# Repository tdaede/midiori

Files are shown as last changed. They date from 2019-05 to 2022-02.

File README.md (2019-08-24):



# Installation

1. Remove a cover plate from a free x68000 expansion slot.
2. Slide card into expansion plate until it seats. It will take some force.
3. Install 3d printed cover plate.
4. Attach OUT connector to MIDI in of your synthesizer.
5. (optional) Run LINE OUT from the x68000 to the LINE IN of your synthesizer's internal mixer.

# Compatibility

A list of tested games is available [here](docs/GAMES.md).

# Changelog

See [here](docs/CHANGELOG.md).

# Differences from midiori v1

- MIDI IN and THRU ports are not implemented.
- FIFO-Rx and FIFO-IRx are not implemented.
- FIFO-ITx start/stop/clock messages are not implemented.
- SYNC and CLICK are not implemented.
- Sequencer is not implemented.
- GPIO is not implemented.
- Address is locked to 0xeafa00.
- IRQ is locked to slot+2.
- Baud rate is locked to 31250 bps, 8n1.
- 32-byte, null terminated version string, readable by writing
  the index (0-31) to 0xF4 and reading the current byte from 0xF5.
- 68k bus is implemented natively and timings are generally faster.

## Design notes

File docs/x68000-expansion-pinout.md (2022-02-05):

# X68000 Expansion Pinout
As described by [_Outside X68000_](https://archive.org/stream/OutsideX680001993/Outside_X68000_1993#page/n51/mode/2up). Translated by Google.

| Pin # | Description | I/O | Comment |
|---|---|-----|---|
|A1 | GND | ... | Ground  |
|A2 | 20MHz | O | 20MHz clock |
|A3 | GND | ... | Ground  |
|A4 | DB0 | I/O | Data bus |
|A5 | DB1 | I/O | Data bus |
|A6 | DB2 | I/O | Data bus |
|A7 | DB3 | I/O | Data bus |
|A8 | DB4 | I/O | Data bus |
|A9 | DB5 | I/O | Data bus |
|A10 | DB6 | I/O | Data bus |
|A11 | GND | ... | Ground  |
|A12 | DB7 | I/O | Data bus |
|A13 | DB8 | I/O | Data bus |
|A14 | DB9 | I/O | Data bus |
|A15 | DB10 | I/O | Data bus |
|A16 | DB11 | I/O | Data bus |
|A17 | DB12 | I/O | Data bus |
|A18 | DB13 | I/O | Data bus |
|A19 | DB14 | I/O | Data bus |
|A20 | DB15 | I/O | Data bus |
|A21 | GND | ... | Ground |
|A22 | +12V | O | +12V DC power supply |
|A23 | +12V | O | +12V DC power supply |
|A24 | FC0 | I/O | Function code |
|A25 | FC1 | I/O | Function code |
|A26 | FC2 | I/O | Function code |
|A27 | ~AS | I/O | Address strobe |
|A28 | ~LDS | I/O | Lower data strobe |
|A29 | ~UDS | I/O | Upper data strobe |
|A30 | R/~W | I/O | Read/write ("L" = Write) |
|A31 | --- | ... | Unused (key?) |
|A32 | -12V | O | -12V DC power supply |
|A33 | -12V | O | -12V DC power supply |
|A34 | ~VMA | O | Address bus enabled |
|A35 | -EXVPA | I | 6800-series peripheral device access signal |
|A36 | ~DTACK | I/O | Data transfer completed |
|A37 | ~EXRESET | O | External reset |
|A38 | ~HALT | I/O | CPU halt request |
|A39 | ~EXBERR | I/O | Bus error |
|A40 | ~EXPWON | I | Soft-power ON request |
|A41 | GND | ... | Ground |
|A42 | Vcc2 | O | +5V standby power (always on) |
|A43 | Vcc2 | O | +5V standby power (always on) |
|A44 | SELEN | O | Row/column address switching |
|A45 | CASRDEN | O | Main memory CAS signal (when reading) |
|A46 | CASWRL | O | CAS signal for writing lower data |
|A47 | CASWRU | O | CAS signal for writing upper data |
|A48 | INH2 | O | Refresh cycle display signal |
|A49 | Vcc1 | O | +5V DC power supply |
|A50 | Vcc1 | O | +5V DC power supply |
|B1 | GND | ... | Ground |
|B2 | 10MHz | O | 10MHz clock signal |
|B3 | ~10MHz | O | 10MHz clock signal (inverted) |
|B4 | E | O | 6800-series peripheral device clock |
|B5 | AB1 | I/O | Address bus |
|B6 | AB2 | I/O | Address bus |
|B7 | AB3 | I/O | Address bus |
|B8 | AB4 | I/O | Address bus |
|B9 | AB5 | I/O | Address bus |
|B10 | AB6 | I/O | Address bus |
|B11 | GND | ... | Ground |
|B12 | AB7 | I/O | Address bus |
|B13 | AB8 | I/O | Address bus |
|B14 | AB9 | I/O | Address bus |
|B15 | AB10 | I/O | Address bus |
|B16 | AB11 | I/O | Address bus |
|B17 | AB12 | I/O | Address bus |
|B18 | AB13 | I/O | Address bus |
|B19 | AB14 | I/O | Address bus |
|B20 | AB15 | I/O | Address bus |
|B21 | GND | ... | Ground |
|B22 | AB16 | I/O | Address bus |
|B23 | AB17 | I/O | Address bus |
|B24 | AB18 | I/O | Address bus |
|B25 | AB19 | I/O | Address bus |
|B26 | AB20 | I/O | Address bus |
|B27 | AB21 | I/O | Address bus |
|B28 | AB22 | I/O | Address bus |
|B29 | AB23 | I/O | Address bus |
|B30 | IDDIR | O | Data bus buffer direction control |
|B31 | --- | ... | Unused (key?) |
|B32 | HSYNC | O | Horizontal sync signal |
|B33 | VSYNC | O | Vertical sync signal |
|B34 | ~DONE | O | DMA block transfer complete |
|B35 | ~DTC | I | DMA data transfer completed |
|B36 | ~EXREQ | I/O | DMA data transfer request |
|B37 | ~EXACK | O | DMA data transfer permission |
|B38 | ~EXPCL | I/O | DMA general purpose I/O signal |
|B39 | ~EXOWN | I/O | Bus release operation signal |
|B40 | ~EXNMI | I | NMI request signal |
|B41 | GND | ... | Ground |
|B42 | ~IRQ2-n | O | Level 2 interrupt request |
|B43 | ~IRQ4-n | O | Level 4 interrupt request |
|B44 | ~IACK2-n | O | Level 2 interrupt acknowledge |
|B45 | ~IACK4-n | O | Level 4 interrupt acknowledge |
|B46 | ~BR-n | O | Bus request |
|B47 | ~BG-n | O | Bus ground |
|B48 | ~BGACK | O | Bus ground acknowledge |
|B49 | Vcc1 | O | +5V DC power supply |
|B50 | Vcc1 | O | +5V DC power supply |

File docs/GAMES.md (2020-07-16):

Known working
---------------
* Akumajou Dracula
* Angel Dive
* Arcus Odyssey (登録)
* Atomic Robo-Kid (F1)
* Bleed Out
* Carat
* Cynthia (V2 only)
* Daimakaimura
* Detana!! TwinBee
* Die Bahnwelt
* Deadly Edge
* Etoile Princesse
* Final Fight
* Garou Densetsu
* Garou Densetsu 2
* Garou Densetsu Special
* Gemini Wing (F1)
* Genocide 2
* Geograph Seal
* Granada (10MHz)
* KU2
* Mahou Daisakusen
* Metal Orange EX
* Nemesis '90 Kai
* Parodius Da! (F3)
* Phalanx
* Sol-Feace (登録)
* Star Luster
* Street Fighter II
* Super Hang-On
* Super Street Fighter II
* Thunder Blade (F5)
* Xenon 2 (登録)

Broken
-------

Unknown
--------
* Gradius II - unknown how to configure
* Duel Fighter 2 - unknown how to configure
* Overtake - crashes on music playback start with both 1.1 and 2.1
* Square Resort - unknown how to configure

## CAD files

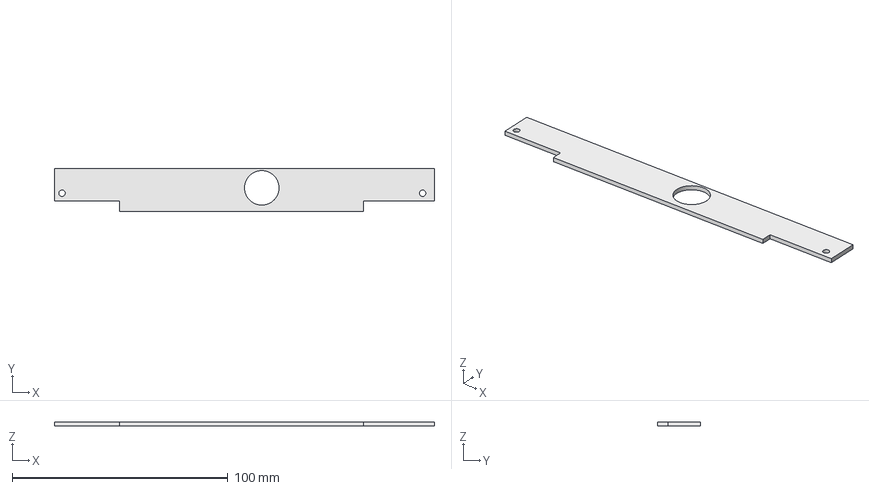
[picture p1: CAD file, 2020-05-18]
mech/midiori_2_plate_minidin_laser.FCStd
176.0 x 20.0 x 2.00 mm

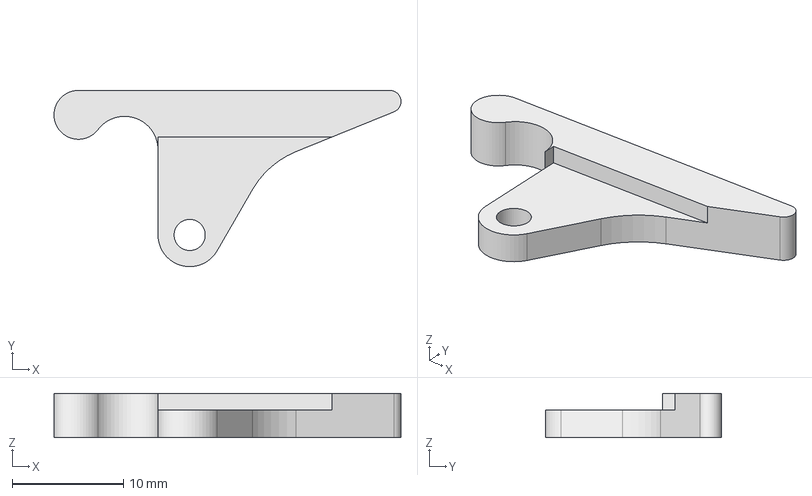
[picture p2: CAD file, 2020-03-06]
mech/x68k_pull.fcstd
31.2 x 15.8 x 4.00 mm

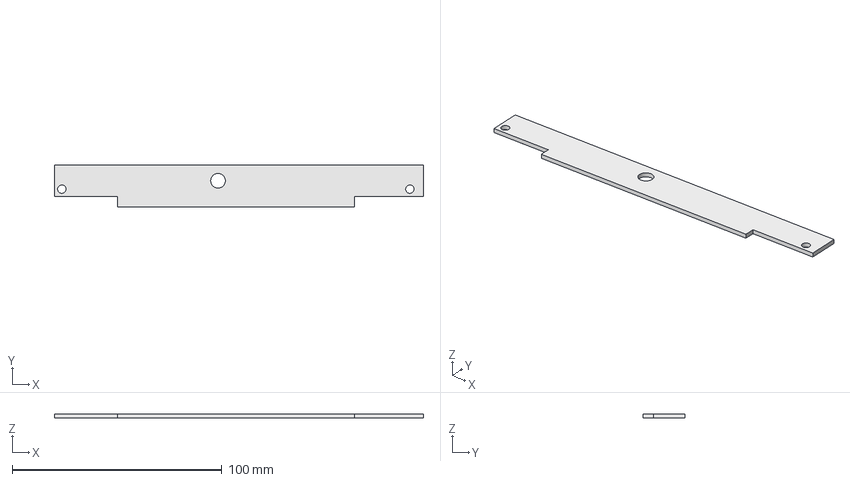
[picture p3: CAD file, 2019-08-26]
mech/midiori_2_plate_trs.FCStd
176.0 x 20.0 x 2.00 mm

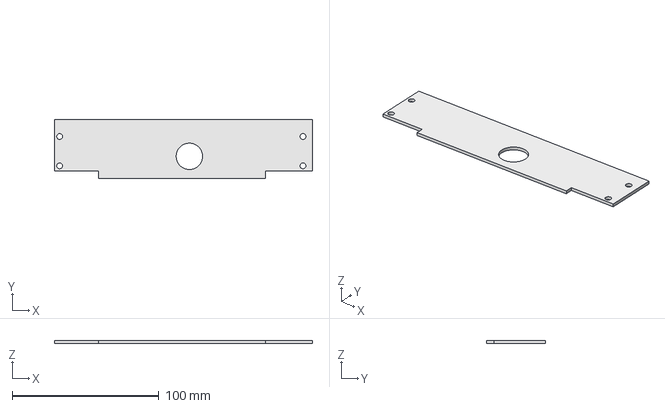
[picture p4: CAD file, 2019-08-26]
mech/midiori_2_plate_din.FCStd
176.0 x 40.0 x 2.00 mm

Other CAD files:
mech/midiori_2_plate_din.stl
mech/midiori_2_plate_trs.stl
mech/x68k_pull.stl

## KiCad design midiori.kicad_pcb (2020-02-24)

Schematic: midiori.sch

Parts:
C1, C2: 4.7uF; C_0805_2012Metric
C3, C4, C5, C6, C7, C9, C10, C11, C12, C13, C14, C15, C16, C17, C18, C19, C20, C21, C22, C23: 0.1uF; C_0805_2012Metric
C8: 0.1uF; C_0805_2012Metric_Pad1.15x1.40mm_HandSolder
H1, H2: MountingHole; MountingHole_3.2mm_M3_Pad
J1: x68000_expansion
J2: Conn_ARM_JTAG_SWD_10; PinHeader_2x05_P1.27mm_Vertical_SMD
J4: Mini-DIN-5; MD-50SM
R3: 10K; R_0805_2012Metric
R6, R9: 220; R_0805_2012Metric_Pad1.15x1.40mm_HandSolder
U1: 74LCX07; SOIC-14_3.9x8.7mm_P1.27mm
U2: AT25SF081-SSHD-X; SOIC-8_3.9x4.9mm_P1.27mm
U3: TLV73312PDBV; SOT-23-5
U4, U5, U6, U7, U8, U9: SN74LVC8T245DWR; SOIC-24W_7.5x15.4mm_P1.27mm
U10: ICE40HX1K-VQ100; QFP50P1600X1600X120-100N
U11: TLV73333PDBV; SOT-23-5
X1: 16MHz; Oscillator_SMD_SeikoEpson_SG8002CA-4Pin_7.0x5.0mm

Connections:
+1V2: C2.1, C16.1, C18.1, C20.1, C22.1, U3.5, U10.11 (VCC), U10.35 (VCC), U10.61 (VCC), U10.77 (VCC)
+3V3: C1.1, C3.1, C5.1, C7.1, C8.1, C10.1, C12.1, C14.1, C17.1, C19.1, C21.1, C23.1, J2.1 (VCC), R3.2, U1.14 (VCC), U2.3 (~WP~/IO2), U2.7 (~HOLD~/IO3), U2.8 (VCC), U3.1, U3.3, U4.23 (VCCB), U4.24 (VCCB), U5.23 (VCCB), U5.24 (VCCB), U6.23 (VCCB), U6.24 (VCCB), U7.23 (VCCB), U7.24 (VCCB), U8.23 (VCCB), U8.24 (VCCB), U9.23 (VCCB), U9.24 (VCCB), U10.6 (VCCIO_3), U10.14 (VCCIO_3), U10.22 (VCCIO_3), U10.31 (VCCIO_2), U10.38 (VCCIO_2), U10.50 (VCC_SPI), U10.58 (VCCIO_1), U10.67 (VCCIO_1), U10.75 (VPP_2V5), U10.88 (VCCIO_0), U10.92 (VCCIO_0), U11.5, X1.1 (OE), X1.4 (V+)
+5V: C4.1, C6.1, C9.1, C11.1, C13.1, C15.1, J1.A49 (+5V), J1.A50 (+5V), J1.B49 (+5V), J1.B50 (+5V), R6.1, U4.1 (VCCA), U4.2 (DIR), U5.1 (VCCA), U5.2 (DIR), U6.1 (VCCA), U6.2 (DIR), U7.1 (VCCA), U8.1 (VCCA), U8.2 (DIR), U9.1 (VCCA), U9.2 (DIR), U11.1, U11.3
/10MHz: J1.B3 (10MHz), U8.3 (A1)
/10m: U8.21 (B1), U10.97 (IOT_91)
/A: J1.A26 (FC2), U8.8 (A6)
/AB1: J1.B5 (AB1), U4.10 (A8)
/AB2: J1.B6 (AB2), U4.9 (A7)
/AB3: J1.B7 (AB3), U4.8 (A6)
/AB4: J1.B8 (AB4), U4.7 (A5)
/AB5: J1.B9 (AB5), U4.6 (A4)
/AB6: J1.B10 (AB6), U4.5 (A3)
/AB7: J1.B12 (AB7), U4.4 (A2)
/AB8: J1.B13 (AB8), U5.10 (A8)
/AB9: J1.B14 (AB9), U5.9 (A7)
/AB10: J1.B15 (AB10), U5.8 (A6)
/AB11: J1.B16 (AB11), U5.7 (A5)
/AB12: J1.B17 (AB12), U5.6 (A4)
/AB13: J1.B18 (AB13), U5.5 (A3)
/AB14: J1.B19 (AB14), U5.4 (A2)
/AB15: J1.B20 (AB15), U5.3 (A1)
/AB16: J1.B22 (AB16), U6.10 (A8)
/AB17: J1.B23 (AB17), U6.9 (A7)
/AB18: J1.B24 (AB18), U6.8 (A6)
/AB19: J1.B25 (AB19), U6.7 (A5)
/AB20: J1.B26 (AB20), U6.6 (A4)
/AB21: J1.B27 (AB21), U6.5 (A3)
/AB22: J1.B28 (AB22), U6.4 (A2)
/AB23: J1.B29 (AB23), U6.3 (A1)
/AS: J1.A27 (/AS), U8.7 (A5)
/B: J1.A25 (FC1), U8.9 (A7)
/C: J1.A24 (FC0), U8.10 (A8)
/DB0: J1.A4 (DB0), U7.10 (A8)
/DB1: J1.A5 (DB1), U7.9 (A7)
/DB2: J1.A6 (DB2), U7.8 (A6)
/DB3: J1.A7 (DB3), U7.7 (A5)
/DB4: J1.A8 (DB4), U7.6 (A4)
/DB5: J1.A9 (DB5), U7.5 (A3)
/DB6: J1.A10 (DB6), U7.4 (A2)
/DB7: J1.A12 (DB7), U7.3 (A1)
/DTACK: J1.A36 (/DTACK), U1.6
/EXRESET: J1.A37 (EXRESET), U8.4 (A2)
/IACK2: J1.B44 (/IACK2), U9.3 (A1)
/IACK4: J1.B45 (/IACK4), U9.4 (A2)
/IDDIR: J1.B30 (IDDIR), U7.2 (DIR), U9.5 (A3)
/IRQ2: J1.B42 (/IRQ2), U1.2
/IRQ4: J1.B43 (/IRQ4), U1.4
/LDS: J1.A28 (/LDS), U8.6 (A4)
/RW: J1.A30 (R/W), U8.5 (A3)
/a: U8.16 (B6), U10.3 (IOL_2A)
/a1: U4.14 (B8), U10.40 (IOB_41)
/a2: U4.15 (B7), U10.37 (IOB_37)
/a3: U4.16 (B6), U10.36 (IOB_34)
/a4: U4.17 (B5), U10.34 (IOB_36_GBIN4)
/a5: U4.18 (B4), U10.33 (IOB_35_GBIN5)
/a6: U4.19 (B3), U10.30 (IOB_30)
/a7: U4.20 (B2), U10.29 (IOB_29)
/a16: U6.14 (B8), U10.81 (IOT_77)
/a17: U6.15 (B7), U10.80 (IOT_75)
/a18: U6.16 (B6), U10.79 (IOT_74)
/a19: U6.17 (B5), U10.78 (IOT_73)
/a20: U6.18 (B4), U10.74 (IOR_72)
/a21: U6.19 (B3), U10.73 (IOR_71)
/a22: U6.20 (B2), U10.72 (IOR_70)
/a23: U6.21 (B1), U10.71 (IOR_69)
/ab8: U5.14 (B8), U10.18 (IOL_8A)
/ab9: U5.15 (B7), U10.16 (IOL_7B)
/ab10: U5.16 (B6), U10.15 (IOL_7A_GBIN6)
/ab11: U5.17 (B5), U10.13 (IOL_6B_GBIN7)
/ab12: U5.18 (B4), U10.12 (IOL_6A)
/ab13: U5.19 (B3), U10.10 (IOL_5B)
/ab14: U5.20 (B2), U10.9 (IOL_5A)
/ab15: U5.21 (B1), U10.8 (IOL_3B)
/as: U8.17 (B5), U10.2 (IOL_1B)
/b: U8.15 (B7), U10.4 (IOL_2B)
/c: U8.14 (B8), U10.7 (IOL_3A)
/d0: U7.14 (B8), U10.28 (IOB_28)
/d1: U7.15 (B7), U10.27 (IOB_27)
/d2: U7.16 (B6), U10.26 (IOB_26)
/d3: U7.17 (B5), U10.25 (IOL_12B)
/d4: U7.18 (B4), U10.24 (IOL_12A)
/d5: U7.19 (B3), U10.21 (IOL_10B)
/d6: U7.20 (B2), U10.20 (IOL_10A)
/d7: U7.21 (B1), U10.19 (IOL_8B)
/dtack: U1.5, U10.93 (IOT_87)
/exreset: U8.20 (B2), U10.99 (IOT_93)
/iack2: U9.21 (B1), U10.94 (IOT_88)
/iack4: U9.20 (B2), U10.95 (IOT_89)
/iddir: U9.19 (B3), U10.96 (IOT_90)
/irq2: U1.1, U10.90 (IOT_85_GBIN0)
/irq4: U1.3, U10.91 (IOT_86)
/lds: U8.18 (B4), U10.1 (IOL_1A)
/reset: J2.8 (NC/TDI), R3.1, U10.44 (CRESET_B)
/rw: U8.19 (B3), U10.100 (IOT_95)
/sck: J2.4 (SWDCLK/TCK), U2.6 (SCK), U10.48 (IOB_46_SCK)
/si: J2.2 (SWDIO/TMS), U2.5 (SI/IO0), U10.45 (IOB_44_SDO)
/so: J2.10 (~RESET~), U2.2 (SO/IO1), U10.46 (IOB_45_SDI)
/ss: J2.6 (SWO/TDO), U2.1 (~CS), U10.49 (IOB_47_SS)
/xltr_oe: U7.22 (OE), U10.51 (IOR_52)
GND: C1.2, C2.2, C3.2, C4.2, C5.2, C6.2, C7.2, C8.2, C9.2, C10.2, C11.2, C12.2, C13.2, C14.2, C15.2, C16.2, C17.2, C18.2, C19.2, C20.2, C21.2, C22.2, C23.2, J1.A1 (GND), J1.A3 (GND), J1.A11 (GND), J1.A21 (GND), J1.A41 (GND), J1.B1 (GND), J1.B11 (GND), J1.B21 (GND), J1.B41 (GND), J2.3 (GND), J2.5 (GND), J2.9 (GNDDetect), J4.2, U1.7 (GND), U1.11, U1.13, U2.4 (GND), U3.2, U4.3 (A1), U4.11 (GND), U4.12 (GND), U4.13 (GND), U4.21 (B1), U4.22 (OE), U5.11 (GND), U5.12 (GND), U5.13 (GND), U5.22 (OE), U6.11 (GND), U6.12 (GND), U6.13 (GND), U6.22 (OE), U7.11 (GND), U7.12 (GND), U7.13 (GND), U8.11 (GND), U8.12 (GND), U8.13 (GND), U8.22 (OE), U9.6 (A4), U9.7 (A5), U9.8 (A6), U9.9 (A7), U9.10 (A8), U9.11 (GND), U9.12 (GND), U9.13 (GND), U9.14 (B8), U9.15 (B7), U9.16 (B6), U9.17 (B5), U9.18 (B4), U9.22 (OE), U10.5 (GND), U10.17 (GND), U10.23 (GND), U10.32 (GND), U10.39 (GND), U10.47 (GND), U10.55 (GND), U10.70 (GND), U10.84 (GND), U10.98 (GND), U11.2, X1.2 (GND)
unnamed: J4.4, R6.2
unnamed: J4.5, R9.1
unnamed: R9.2, U1.8
unnamed: U1.9, U10.66 (IOR_65)
unnamed: U10.63 (IOR_61_GBIN2), X1.3 (OUT)

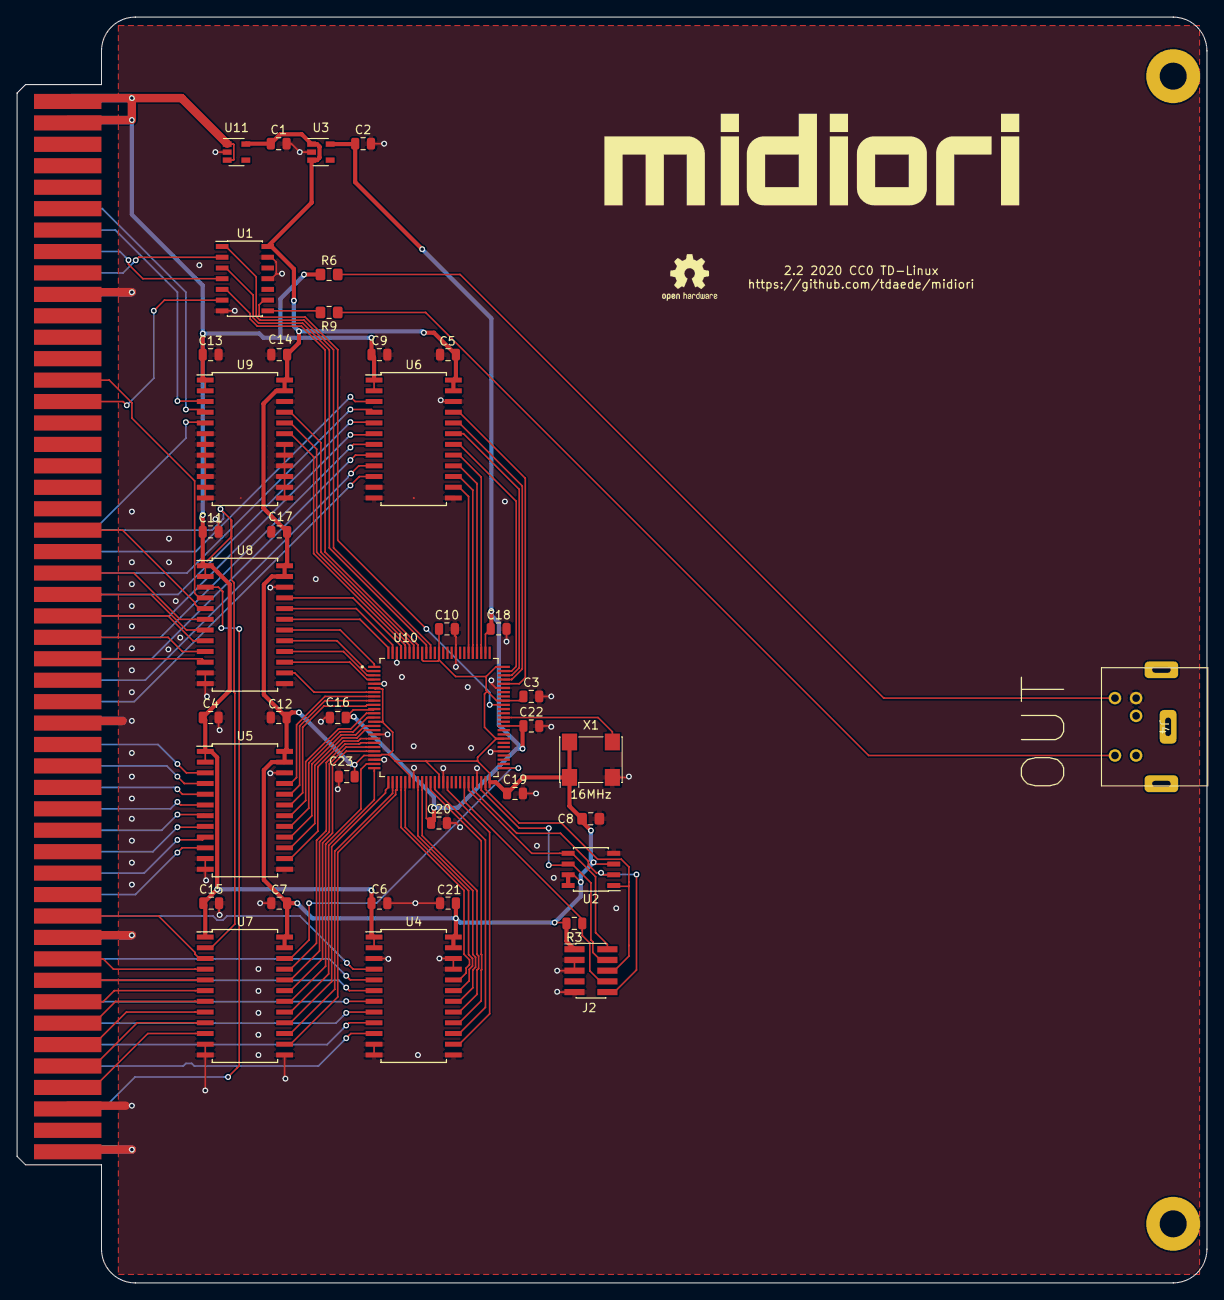
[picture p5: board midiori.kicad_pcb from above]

Board: 2 copper layers, 141.0 x 150.0 mm, 44 parts (0 on the bottom side), 105 nets.

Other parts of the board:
svg2mod: G***; midiori_logo

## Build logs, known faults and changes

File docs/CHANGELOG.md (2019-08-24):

2.1.0
------

Board revision: 2.1

- Initial FPGA-based release.

2.0
----

Unreleased prototype.

1.1
---

YM3802-X based version.

1.0
---

Unreleased prototype.

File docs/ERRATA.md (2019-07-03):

v2.1
-----
* One ground missing on U8
* ss and sck swapped on programming headers
* no way to reset fpga via tagconnect
* board house couldn't bevel fishtail edge

v2.0
-----
Extensive rework required. Only one made.

v1.1
-----
No known errors

v1.0
-----
Extensive rework required. Only one made.

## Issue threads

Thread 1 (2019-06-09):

Card not recognized

wstevens0n, 2019-06-09:
I'm having issues with this card not being recognized on my X68000 Super HD.

Anyway to troubleshoot?

tdaede, 2019-06-09:
Version 1.x or 2.x? Did you build it yourself?

wstevens0n, 2019-06-09:
Howdt TD,

It is a V1.1

I purchased the X68000 with the card preinstalled, but the previous owner said he never used it. He did mention it was ordered thru you.

tdaede, 2019-06-10:
Can you run db.x, and then tell me what the following command prints:
```
mes eafa00
```

wstevens0n, 2019-06-10:
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

tdaede, 2019-06-10:
OK, so the card is responding normally. What game are you trying to use with it? Many require a menu setting or holding a key during start.

wstevens0n, 2019-06-10:
I tried a few from this list
https://en.m.wikipedia.org/wiki/List_of_MT-32-compatible_computer_games

I was able to get games to recognize the module from internal to midi after cleaning the ports with some deoxit.

I am using a sc-55mk2 and confirmed output on the module is functioning via demo mod. However it seems there is no audio being received or recognized from the midori's midi output.

What else can I do to test?

Thanks again for the help.

tdaede, 2019-06-10:
You're using the MIDI OUT port, right (the center one)? Connected to the SC-55mk2's IN?

If games are recognizing the device it's likely a cabling issue.

wstevens0n, 2019-06-10:
Yes it's the correct wiring like your diagram.

I'm now wondering if it's the TRS to 5 DIN adapter cable I purchased.
Is this the correct pinout for female DIN?

3, 1 - None
5 - TX
2 - GND
4 - VD

tdaede, 2019-06-10:
That's the correct DIN pinout, but there are two ways to do the 3.5mm bit. Midiori uses Type A (Korg/Akai)

wstevens0n, 2019-06-11:
Hey TD,

We are good to close the issue. I soldered DIN socket and it solved everything completely. The TRS I purchased had purchased was incorrect.

Thanks again!

tdaede, 2019-06-11:
Great!

I'm considering switching the adapter to 2.5mm on a future version because there is only 1 common wiring for that. Or possibly only using DIN sockets.

Closed 2019-06-11.

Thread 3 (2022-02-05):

Pinout of the 5pin miniDIN

mobiusstriptech, 2022-02-05:
Do you have a diagram or a schematic that explains the pinout for the 5pin miniDIN? I have been trying to make an adapter cable to work with a full size 5 pin DIN and have not had any luck.

tdaede, 2022-02-05:
It is 1:1 pin numbering. It's really annoying to make as 5 pin miniDIN is pretty uncommon nowadays (I actually have some cards remaining to sell, but the annoyance of having to make a bunch of adapters has caused me to put it off...).

mobiusstriptech, 2022-02-05:
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
So this is what I used, but my SC55 doesn't seem to see a signal. I guess I need to investigate further.

mobiusstriptech, 2022-02-05:
Do you know if this has ever been tested on a x68030? That is what I am using. When I load Castlevania it asks me which audio output to use, but no matter what midi unit I select, I get no output.

tdaede, 2022-02-05:
Do you have a way to write disk images or transfer files? I can send you a test program to make sure the card is working.

mobiusstriptech, 2022-02-05:
Unfortunately I don't right now. I am making the assumption that the Midiori is working at least partially. Since Castlevania asks me to choose the audio output. I should be able to test this cable with an original midi card later this week.

tdaede, 2022-02-05:
If it detects it then it's at least working partially. I have never tested on X68030 but the test program should find most problems. FWIW pins 2, 4, and 5 are the only ones that actually matter. Did you get one that was manufactured by me or by someone else?

mobiusstriptech, 2022-02-05:
I built it myself. I didn't see you selling them anymore but wanted to try one. I could ask a friend to write a floppy for me if that would work. One of my friends has the ability to do so.

tdaede, 2022-02-05:
Yeah I just wanted to check if there were any construction errors we could potentially watch for as well. It would be good to run the test program to separate problems with the bus and MIDI chip emulation, and problems talking to your synth. I'll see if I can put the files in the repo.

mobiusstriptech, 2022-02-06:
I built a new Midiori today but still am not able to get my devices working. At this point I'm assuming it's a cable or device issue. Hopefully I didn't kill the optocouplers or worse with a backwards wire.

mobiusstriptech, 2022-02-08:
Got a new cable today and confirmed that the midi units are testing good with the built in loopback tests. I'm starting to wonder if there is an incompatibility with the x68030?

mobiusstriptech, 2022-02-08:
I found the issue. It was definitely the cable. Can confirm that Midiori works with x68030.

tdaede, 2022-02-09:
Great!

Closed 2022-02-08.

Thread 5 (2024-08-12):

Midiori ver 1.1 not detected

suk2013, 2024-08-12:
Hi,
I don't know where to post my questions below and I couldn't find the Discussions link so I opened an issue.
I built a Midiori ver 1.1 and I tested it on my x68K computer but it wasn't detected. Do I need to program anything to the components? I wonder if it's because some components not soldered properly or I used the incorrect components. I attached list of components that I used. The capacitor value that I used was 0.1uF (I assumed u1 is 0.1uF).  I saw other closed issue was suggested to use db.x program but I have no idea where to get this. Any help would be appreciated.
[Midiori Parts.pdf](https://github.com/user-attachments/files/16590473/Midiori.Parts.pdf)

tdaede, 2024-08-12:
There is nothing to be programmed. It has been a while since I built a 1.1 but it should just work. Did you get your YM3802-X from a trustworthy source? Fakes are very common.

suk2013, 2024-08-12:
Thank you for your reply. I got it from utsource. It seems a trustworthy source.

suk2013, 2024-08-20:
Thomas, I was able to get my midiori card to work. I soldered manually all components on another pcb. Previosly I used solder paste and hot air gun. It was my first time using this method. I'm not sure if it's because of my soldering work error or there is an issue with my edge connector. It wasn't beveled so I used filing tool to bevel it. The bevel wasn't equal on both top and bottom. The new pcb I beveled both sides more equally. I'm happy that I can get it to work. Thank you so much to you and Mike.
I have some questions:
1. Is it easy to modify the pcb design with Kicad from  midi din connectors to mini din? (I'm not an electrical engineer and I've never designed a pcb).
2. I assume the TRS connector can only connect with TRS to midi adapter/cable, correct? I can't use it with TRS to RCA cable, right?
3. How do I test the card if it's working correctly? So far I can only test with games directly with my x68k computer.

Closed 2024-08-25.

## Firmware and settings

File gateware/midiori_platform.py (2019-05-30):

from migen.build.generic_platform import *
from migen.build.lattice import LatticePlatform


__all__ = ['Platform']


_io = [
    ("sclk", 0, Pins("63"), IOStandard("LVCMOS33")),
    ("rw", 0, Pins("100"), IOStandard("LVCMOS33")),
    ("exreset", 0, Pins("99"), IOStandard("LVCMOS33")),
    ("ioclk", 0, Pins("97"), IOStandard("LVCMOS33")),
    ("iddir", 0, Pins("96"), IOStandard("LVCMOS33")),
    ("iack4", 0, Pins("95"), IOStandard("LVCMOS33")),
    ("iack2", 0, Pins("94"), IOStandard("LVCMOS33")),
    ("dtack", 0, Pins("93"), IOStandard("LVCMOS33")),
    ("irq4", 0, Pins("91"), IOStandard("LVCMOS33")),
    ("irq2", 0, Pins("90"), IOStandard("LVCMOS33")),
    ("lds", 0, Pins("1"), IOStandard("LVCMOS33")),
    ("as", 0, Pins("2"), IOStandard("LVCMOS33")),
    ("a", 0, Pins("3"), IOStandard("LVCMOS33")),
    ("b", 0, Pins("4"), IOStandard("LVCMOS33")),
    ("c", 0, Pins("7"), IOStandard("LVCMOS33")),

    ("addr", 0, Pins("40 37 36 34 33 30 29 18 16 15 13 12 10 9 8 81 80 79 78 74 73 72 71"), IOStandard("LVCMOS33")),
    ("data", 0, Pins("28 27 26 25 24 21 20 19"), IOStandard("LVCMOS33")),

    ("xltr_oe", 0, Pins("51"), IOStandard("LVCMOS33")),
    ("tx", 0, Pins("66"), IOStandard("LVCMOS33"))
]

_connectors = [
]


class Platform(LatticePlatform):
    default_clk_name = "sclk"
    default_clk_period = 1e9 / 16e6

    def __init__(self):
        LatticePlatform.__init__(self, "ice40-hx1k-vq100", _io, _connectors,
                                 toolchain="icestorm")

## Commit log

2018-11-30 Add footprints
    [midiori.kicad_pcb, midiori.sch]
2018-11-30 Add board outline
    [midiori.kicad_pcb, midiori.sch]
2018-12-01 Remove 74ls133 from address decoding
    [midiori.kicad_pcb, midiori.sch]
2018-12-23 silkscreen improvements
    [midiori.kicad_pcb]
2018-12-24 ground unused inputs
    [midiori.kicad_pcb, midiori.sch]
2019-01-20 Move IN THRU OUT labels
    [midiori.kicad_pcb]
2019-02-02 pretty up some traces
    [midiori.kicad_pcb]
2019-02-26 Add pulls
    [x68k_pull.fcstd, x68k_pull.stl]
2019-04-23 PCB layout of fpga version
    [midiori.kicad_pcb, midiori.sch]
2019-04-23 route board
    [midiori.kicad_pcb, midiori.sch]
2019-05-31 Update readme with current implementation details
2019-06-02 Working interrupts
2019-06-03 midiori v2.1 pcb
    [midiori.kicad_pcb, midiori.sch]
2019-06-03 Hide J1 text
    [midiori.kicad_pcb]
2019-06-05 PCB outline fixes
    [midiori.kicad_pcb]
2019-06-16 Fix sck/ss on schematic
    [midiori.sch]
2019-06-16 set solder mask minimum width to 0
    [midiori.kicad_pcb]
2019-07-13 Implement general purpose timer
2019-07-13 update readme with current impl
2019-08-20 Add midi clock counter.
    Click counter is also added but it's not wired up yet
    due to not having the isr mux.
2019-08-26 Add back plate mechanical files
    [midiori_2_plate_din.FCStd, midiori_2_plate_din.stl, midiori_2_plate_trs.FCStd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]
2020-02-24 add more connectors
    [midiori.kicad_pcb, midiori.sch]
2020-02-24 one connector
    [midiori.kicad_pcb, midiori.sch]
2020-02-24 more improvements
    [midiori.kicad_pcb]
2020-02-24 update zones
    [midiori.kicad_pcb]
2020-02-24 some changes
    [midiori.sch]
2020-03-06 Update packing label
    [x68k_pull.fcstd, x68k_pull.stl]
2020-05-18 Add minidin plate
    [midiori_2_plate_minidin_laser.FCStd]
2022-02-05 Add names to X68K expansion connector symbol (#2)
    * Add names to X68K exp conn
    * A1..50 translated
    * Complete b-side of expansion pinout
    * Remove screenshot of Outside X68000

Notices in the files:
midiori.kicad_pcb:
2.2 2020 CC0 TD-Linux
